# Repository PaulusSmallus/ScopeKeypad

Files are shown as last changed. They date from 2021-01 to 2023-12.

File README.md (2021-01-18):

# ScopeKeypad
This project is to create a keypad for use with a PicoScope. The idea is to have a traditional interface to use with oscilloscope software.

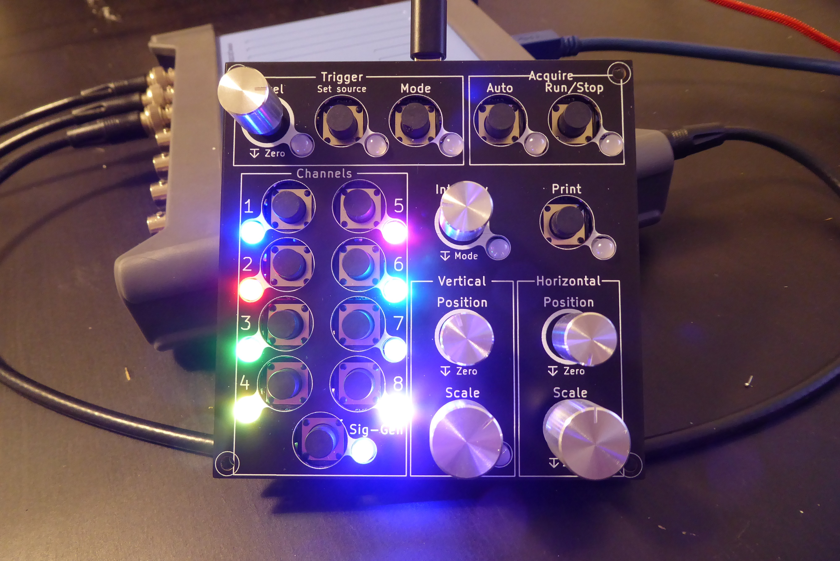
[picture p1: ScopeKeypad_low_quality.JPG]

https://youtu.be/zDIKAT928zg

To use:
Make circuit
	- get the 'main_pcb' made. (in the Hardware/gerbers folder)
	- get one of the 'front_panels' made. There is one for 7mm buttons, and one for 12mm buttons.
	- Solder all the components on
	- Solder JP1 and JP2 depending on if you brought Sparkfun or Worldsemi LEDs (they have different pinouts -_- ).
upload firmware
	- Install Arduino_STM32 ( https://github.com/rogerclarkmelbourne/Arduino_STM32 )
	- Open ScopeKeypad\Firmware\ScopeKeypad_Firmware\ScopeKeypad_Firmware.ino
	- Upload firmware with settings:
		- Board: "Generic STM32F103C"
		- Variant: "STM32F103C8 (20k RAM, 65k Flash)"
		- Upload method: "STLink"
		- CPU Speed(MHz): "72Mhz (normal)"
		- Optimize: "Smallest (default)"
upload shortcut settings to PicoScope software
	- Open PicoScope
	- Click 'Tools'
	- Click 'Preferences...'
	- Open the 'Keyboard' tab
	- Under 'Select keyboard map.', select 'import'
	- Open 'picoscope_shortcuts.pskeys'

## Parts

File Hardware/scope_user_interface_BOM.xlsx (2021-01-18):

Reference | Quantity | Value | Footprint | Datasheet | Cost ea | Cost total | link | lcsc number | part number
C1 C4 C2 C5 C3 C6 C7 C10 C8 C11 C9 C12 C13 C15 C14 C16 | 16 | 1nF | Capacitor_SMD:C_0805_2012Metric |  | £0.0042 | £0.07 | https://lcsc.com/product-detail/Multilayer-Ceramic-Capacitors-MLCC-SMD-SMT_CCTC-TCC0805X7R102M500DT_C713510.html | C713510 | Generic
D20 D18 D19 D23 D21 D22 D24 D25 D1 D2 D3 D4 D5 D6 D7 D8 D9 D10 D11 D12 D13 D14 D15 D16 D17 | 25 | D | Diode_SMD:D_SOD-123F |  | £0.01 | £0.13 | https://lcsc.com/product-detail/Diodes-General-Purpose_Shandong-Jingdao-Microelectronics-1N4007W_C108803.html | C108803 | Generic
D26 D27 D28 D29 D30 D31 D32 D33 D34 D35 D36 D37 D38 D39 D40 D41 D42 D43 | 18 | NeoPixel_THT | LED_THT:LED_D5.0mm-4_RGB | https://www.adafruit.com/product/1938 | £0.12 | £2.15 | https://lcsc.com/product-detail/Others_WS2812D-F5_C190565.html | C190565 | WS2812D-F5
J1 | 1 | USB_B | Connector_USB:USB_B_OST_USB-B1HSxx_Horizontal |  | £0.55 | £0.55 | https://lcsc.com/product-detail/USB-Connectors_MOLEX_47346-0001_47346-0001_C132560.html | C132560 | MOLEX 473460001
R12 R13 R14 R15 R16 R17 R24 R25 R26 R27 R28 R29 R34 R35 R36 R37 | 16 | 100R | Resistor_SMD:R_0805_2012Metric |  |  | £0.00 |  |  | generic
R38 R39 | 2 | 22R | Resistor_SMD:R_0805_2012Metric |  |  | £0.00 |  |  | generic
R9 R6 R10 R7 R11 R8 R21 R18 R22 R19 R23 R20 R32 R30 R33 R31 R1 R2 R3 R4 R5 | 21 | 10k | Resistor_SMD:R_0805_2012Metric |  |  | £0.00 |  |  | generic
SW1 SW2 SW3 SW4 SW5 SW6 SW7 SW8 SW9 SW10 SW11 SW12 SW13 SW14 SW15 SW16 SW17 | 17 | SW_Push | Button_Switch_THT:SW_PUSH-12mm |  | £0.06 | £0.99 | https://lcsc.com/product-detail/Tactile-Switches_USAKRO-UK-B0224-G9-250_C780506.html | C780506UK-B0224-G9-250 | C780506
SW20 SW18 SW19 SW23 SW21 SW22 SW25 SW24 | 8 | Rotary_Encoder_Switch | Rotary_Encoder:RotaryEncoder_Alps_EC11E-Switch_Vertical_H20mm | ~ | £1.67 | £13.35 | https://lcsc.com/product-detail/Coded-Rotary-Switches_ALPS-Electric-EC11E09244AQ_C470753.html | C470753 | EC11E09244AQ
TP1 | 1 | TestPoint |  | ~ |  | £0.00
U1 | 1 | bluepill | footprints:DIP-40_15.24_generic |  |  | £0.00 |  | aliexpress?
 |  |  | rotary dial cap
 |  |  |  |  | TOTAL | £17.22

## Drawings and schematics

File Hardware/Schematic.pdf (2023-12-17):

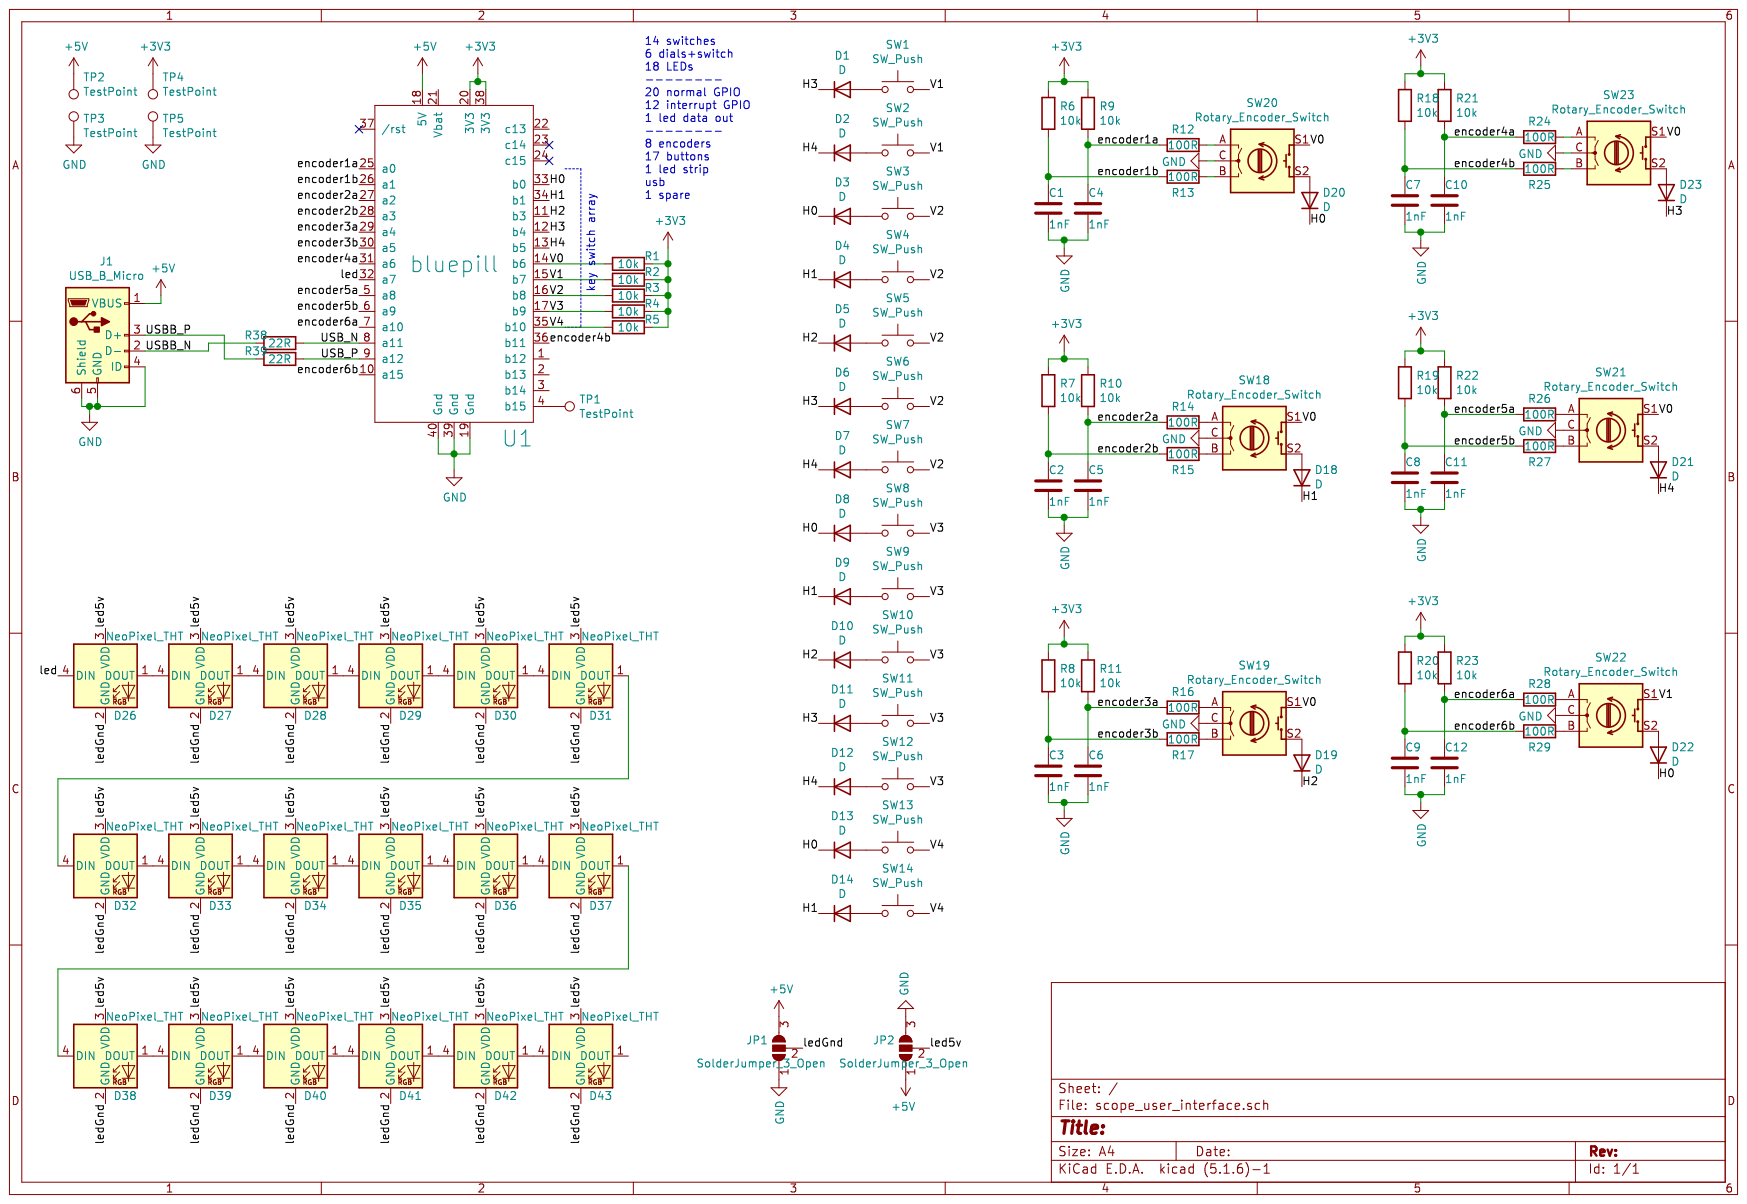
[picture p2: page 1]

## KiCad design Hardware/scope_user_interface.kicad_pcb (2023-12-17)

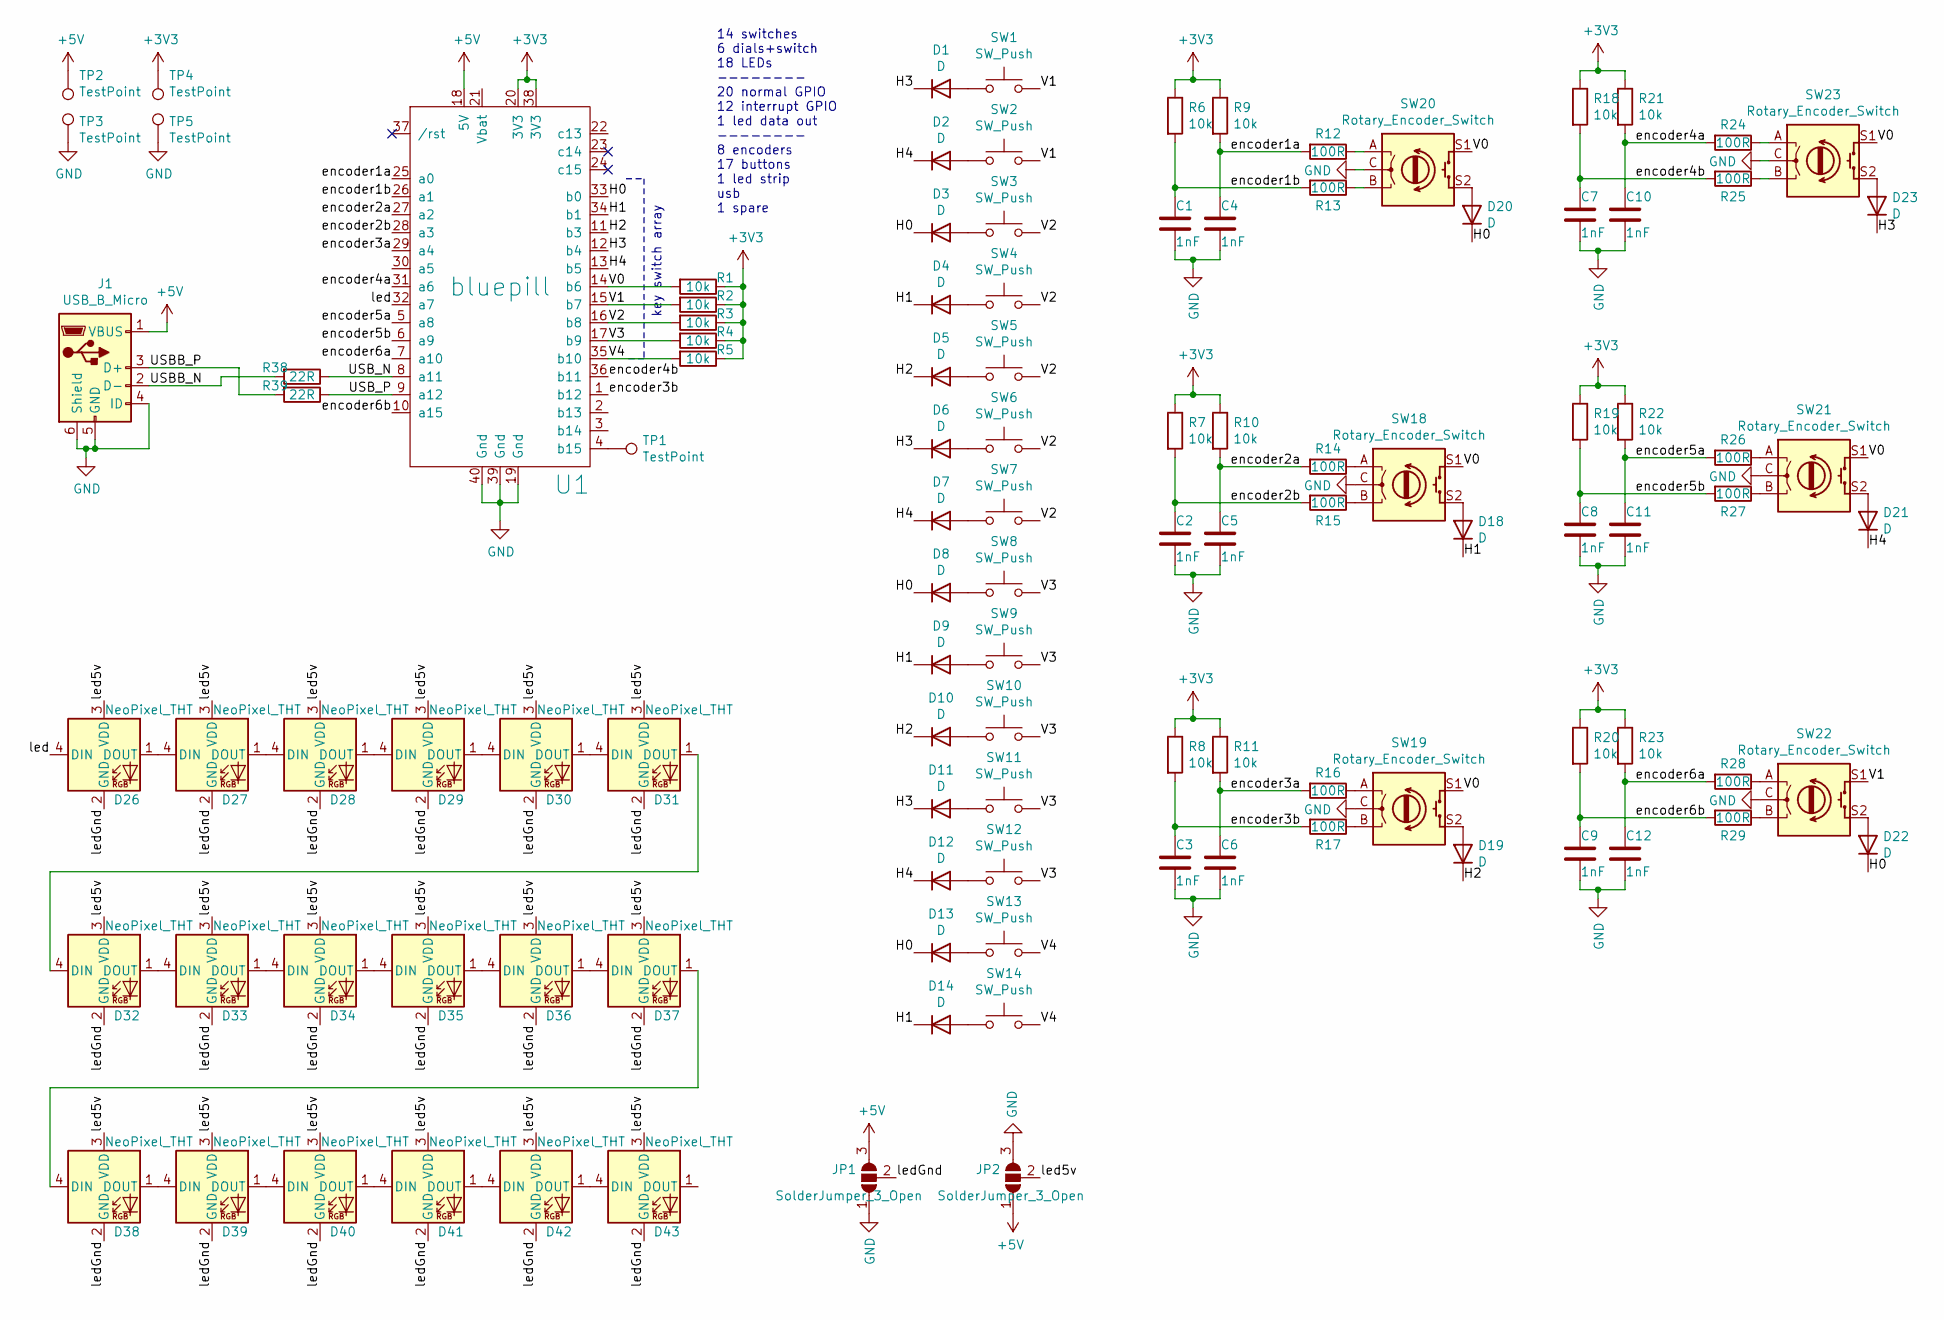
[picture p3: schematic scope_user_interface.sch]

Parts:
C1, C2, C3, C4, C5, C6, C7, C8, C9, C10, C11, C12: 1nF; C_0805_2012Metric
D1, D2, D3, D4, D5, D6, D7, D8, D9, D10, D11, D12, D13, D14, D18, D19, D20, D21, D22, D23: D; D_SOD-123F
D26, D27, D28, D29, D30, D31, D32, D33, D34, D35, D36, D37, D38, D39, D40, D41, D42, D43: NeoPixel_THT; LED_D5.0mm-4_RGB
J1: USB_B_Micro; USB_Micro-B_Molex_47346-0001
JP1, JP2: SolderJumper_3_Open; SolderJumper-3_P1.3mm_Open_RoundedPad1.0x1.5mm
R1, R2, R3, R4, R5, R6, R7, R8, R9, R10, R11, R18, R19, R20, R21, R22, R23: 10k; R_0805_2012Metric
R12, R13, R14, R15, R16, R17, R24, R25, R26, R27, R28, R29: 100R; R_0805_2012Metric
R38, R39: 22R; R_0805_2012Metric
SW1, SW2, SW3, SW4, SW5, SW6, SW7, SW8, SW9, SW10, SW11, SW12, SW13, SW14: SW_Push; SW_PUSH-12mm
SW18, SW19, SW20, SW21, SW22, SW23: Rotary_Encoder_Switch; RotaryEncoder_Alps_EC11E-Switch_Vertical_H20mm
TP1, TP2, TP3, TP4, TP5: TestPoint; TestPoint_Loop_D2.50mm_Drill1.85mm
U1: bluepill; DIP-40_15.24_generic

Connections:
+3V3: R1.1, R2.1, R3.1, R4.1, R5.1, R6.1, R7.1, R8.1, R9.1, R10.1, R11.1, R18.1, R19.1, R20.1, R21.1, R22.1, R23.1, TP4.1, U1.20 (3V3), U1.38 (3V3)
+5V: J1.1 (VBUS), JP1.3 (B), JP2.1 (A), TP2.1, U1.18 (5V)
/H0: D3.1 (K), D8.1 (K), D13.1 (K), D20.1 (K), D22.1 (K), U1.33 (b0)
/H1: D4.1 (K), D9.1 (K), D14.1 (K), D18.1 (K), U1.34 (b1)
/H2: D5.1 (K), D10.1 (K), D19.1 (K), U1.11 (b3)
/H3: D1.1 (K), D6.1 (K), D11.1 (K), D23.1 (K), U1.12 (b4)
/H4: D2.1 (K), D7.1 (K), D12.1 (K), D21.1 (K), U1.13 (b5)
/USBB_N: J1.2 (D-), R38.2
/USBB_P: J1.3 (D+), R39.2
/USB_N: R38.1, U1.8 (a11)
/USB_P: R39.1, U1.9 (a12)
/V0: R1.2, SW18.S1, SW19.S1, SW20.S1, SW21.S1, SW23.S1, U1.14 (b6)
/V1: R2.2, SW1.2, SW2.2, SW22.S1, U1.15 (b7)
/V2: R3.2, SW3.2, SW4.2, SW5.2, SW6.2, SW7.2, U1.16 (b8)
/V3: R4.2, SW8.2, SW9.2, SW10.2, SW11.2, SW12.2, U1.17 (b9)
/V4: R5.2, SW13.2, SW14.2, U1.35 (b10)
/encoder1a: C4.1, R9.2, R12.2, U1.25 (a0)
/encoder1b: C1.1, R6.2, R13.2, U1.26 (a1)
/encoder2a: C5.1, R10.2, R14.2, U1.27 (a2)
/encoder2b: C2.1, R7.2, R15.2, U1.28 (a3)
/encoder3a: C6.1, R11.2, R16.2, U1.29 (a4)
/encoder3b: C3.1, R8.2, R17.2, U1.1 (b12)
/encoder4a: C10.1, R21.2, R24.2, U1.31 (a6)
/encoder4b: C7.1, R18.2, R25.2, U1.36 (b11)
/encoder5a: C11.1, R22.2, R26.2, U1.5 (a8)
/encoder5b: C8.1, R19.2, R27.2, U1.6 (a9)
/encoder6a: C12.1, R23.2, R28.2, U1.7 (a10)
/encoder6b: C9.1, R20.2, R29.2, U1.10 (a15)
/led: D26.4 (DIN), U1.32 (a7)
/led5v: D26.3 (VDD), D27.3 (VDD), D28.3 (VDD), D29.3 (VDD), D30.3 (VDD), D31.3 (VDD), D32.3 (VDD), D33.3 (VDD), D34.3 (VDD), D35.3 (VDD), D36.3 (VDD), D37.3 (VDD), D38.3 (VDD), D39.3 (VDD), D40.3 (VDD), D41.3 (VDD), D42.3 (VDD), D43.3 (VDD), JP2.2 (C)
/ledGnd: D26.2 (GND), D27.2 (GND), D28.2 (GND), D29.2 (GND), D30.2 (GND), D31.2 (GND), D32.2 (GND), D33.2 (GND), D34.2 (GND), D35.2 (GND), D36.2 (GND), D37.2 (GND), D38.2 (GND), D39.2 (GND), D40.2 (GND), D41.2 (GND), D42.2 (GND), D43.2 (GND), JP1.2 (C)
GND: C1.2, C2.2, C3.2, C4.2, C5.2, C6.2, C7.2, C8.2, C9.2, C10.2, C11.2, C12.2, J1.4 (ID), J1.5 (GND), J1.6 (Shield), JP1.1 (A), JP2.3 (B), SW18.C, SW19.C, SW20.C, SW21.C, SW22.C, SW23.C, TP3.1, TP5.1, U1.19 (Gnd), U1.39 (Gnd), U1.40 (Gnd); also elsewhere on the board
unnamed: D1.2 (A), SW1.1
unnamed: D2.2 (A), SW2.1
unnamed: D3.2 (A), SW3.1
unnamed: D4.2 (A), SW4.1
unnamed: D5.2 (A), SW5.1
unnamed: D6.2 (A), SW6.1
unnamed: D7.2 (A), SW7.1
unnamed: D8.2 (A), SW8.1
unnamed: D9.2 (A), SW9.1
unnamed: D10.2 (A), SW10.1
unnamed: D11.2 (A), SW11.1
unnamed: D12.2 (A), SW12.1
unnamed: D13.2 (A), SW13.1
unnamed: D14.2 (A), SW14.1
unnamed: D18.2 (A), SW18.S2
unnamed: D19.2 (A), SW19.S2
unnamed: D20.2 (A), SW20.S2
unnamed: D21.2 (A), SW21.S2
unnamed: D22.2 (A), SW22.S2
unnamed: D23.2 (A), SW23.S2
unnamed: D26.1 (DOUT), D27.4 (DIN)
unnamed: D27.1 (DOUT), D28.4 (DIN)
unnamed: D28.1 (DOUT), D29.4 (DIN)
unnamed: D29.1 (DOUT), D30.4 (DIN)
unnamed: D30.1 (DOUT), D31.4 (DIN)
unnamed: D31.1 (DOUT), D32.4 (DIN)
unnamed: D32.1 (DOUT), D33.4 (DIN)
unnamed: D33.1 (DOUT), D34.4 (DIN)
unnamed: D34.1 (DOUT), D35.4 (DIN)
unnamed: D35.1 (DOUT), D36.4 (DIN)
unnamed: D36.1 (DOUT), D37.4 (DIN)
unnamed: D37.1 (DOUT), D38.4 (DIN)
unnamed: D38.1 (DOUT), D39.4 (DIN)
unnamed: D39.1 (DOUT), D40.4 (DIN)
unnamed: D40.1 (DOUT), D41.4 (DIN)
unnamed: D41.1 (DOUT), D42.4 (DIN)
unnamed: D42.1 (DOUT), D43.4 (DIN)
unnamed: R12.1, SW20.A
unnamed: R13.1, SW20.B
unnamed: R14.1, SW18.A
unnamed: R15.1, SW18.B
unnamed: R16.1, SW19.A
unnamed: R17.1, SW19.B
unnamed: R24.1, SW23.A
unnamed: R25.1, SW23.B
unnamed: R26.1, SW21.A
unnamed: R27.1, SW21.B
unnamed: R28.1, SW22.A
unnamed: R29.1, SW22.B
unnamed: TP1.1, U1.4 (b15)

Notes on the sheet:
14 switches 6 dials+switch 18 LEDs -------- 20 normal GPIO 12 interrupt GPIO 1 led data out -------- 8 encoders 17 buttons 1 led strip usb 1 spare
key switch array

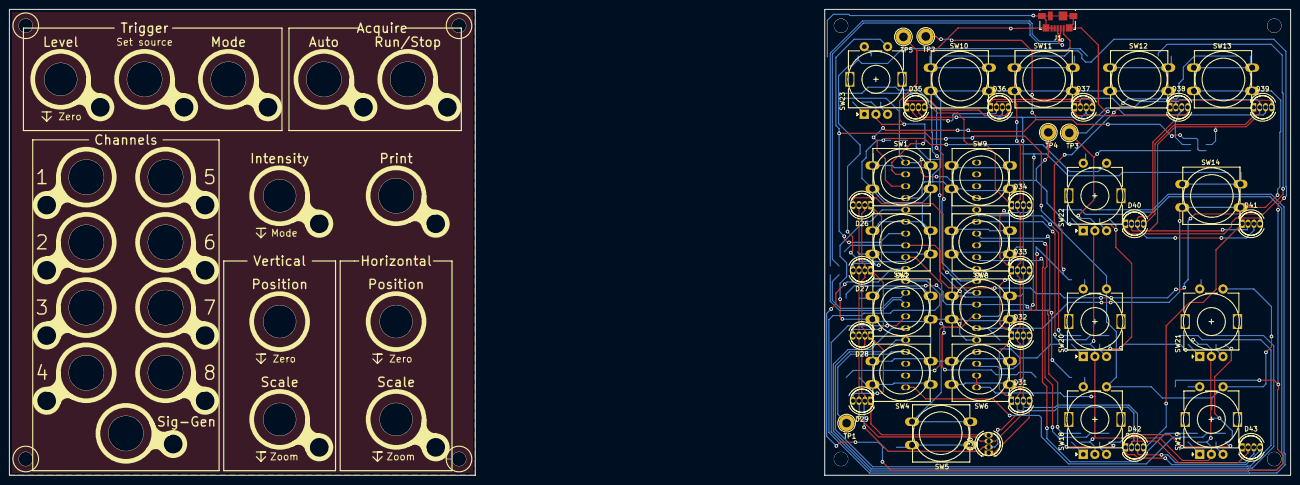
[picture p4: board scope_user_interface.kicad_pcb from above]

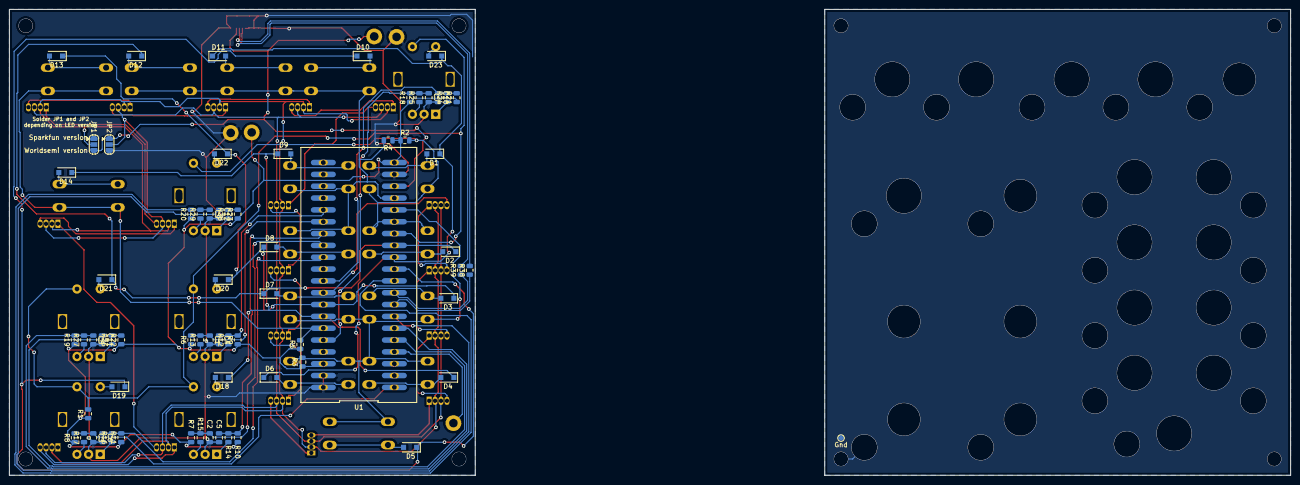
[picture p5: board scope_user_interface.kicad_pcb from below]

Board: 2 copper layers, 100.0 x 100.0 mm, 111 parts (67 on the bottom side), 82 nets.

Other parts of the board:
Gnd: TestPoint_Pad_D1.0mm

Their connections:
GND: Gnd.1; also elsewhere on the board

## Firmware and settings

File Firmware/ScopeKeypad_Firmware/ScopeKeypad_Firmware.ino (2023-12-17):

/*-----------------------NOTES-----------------------
 * requires: https://github.com/rogerclarkmelbourne/Arduino_STM32
 * 
 * TODO:  Change keyboard shortcuts from using 'Alt', as this sometimes causes issues. Use 'Ctrl' and 'Shift' only.
 *        Redo firmware, but with better way of selecting different options.
 *---------------------------------------------------
 */


//**************************************************************
//* include one of these options, depending on software
//**************************************************************

#include "Picoscope.h"
//#include "Pulseview.h"

//*************************************************************


#include <USBComposite.h>
#include <WS2812B.h>

USBHID HID;
HIDKeyboard Keyboard(HID);
USBCompositeSerial CompositeSerial;

#define NUM_LEDS 18
WS2812B strip = WS2812B(NUM_LEDS);
int lo_led[][3] = {{0,0,0},{0,0,0},{0,0,0},{0,0,0},{0,0,0},{0,0,0},{0,2,0},{0,0,0},{0,0,0},{0, 0, 51},{0, 51, 0},{51, 0, 0},{51, 51, 0},{10, 10, 10},{0, 25, 51},{10, 10, 10},{51, 0, 51},{0, 51, 25},{0,0,0},{0,0,0},{0,0,0},{0,0,0},{0,0,0},{0,0,0},{0,0,0},{0,0,0},{0,0,0}};
int hi_led[][3] = {{0,0,0},{0,0,0},{0,0,0},{0,0,0},{0,0,0},{0,0,0},{0,30,0},{0,0,0},{0,0,0},{0, 0,102},{0,102,0},{102,0, 0},{102,102,0},{30, 30, 30},{0, 51, 102},{30, 30, 30},{102,0,102},{0,102, 51},{0,0,0},{0,0,0},{0,0,0},{0,0,0},{0,0,0},{0,0,0},{0,0,0},{0,0,0},{0,0,0}};

int output_buttons[5] = {PB0, PB1, PB3, PB4, PB5};
int input_buttons[5] = {PB6, PB7, PB8, PB9, PB10};
int encoderA_inputs[6] = {PA0, PA2, PA4, PA6, PA8, PA10};
int encoderB_inputs[6] = {PA1, PA3, PB12, PB11, PA9, PA15};

bool channelEnabled [9] = {0,0,0,0,0,0,0,0,0};
char channelSelected = 0; //0 is nothing selected

int8_t buttonToLed[26] = {0,0,0,0,0,0,3,0,0,17,16,15,14,13,12,11,10,9,0,0,0,0,0,0,0,0};
int8_t encoderToLed[6] = {0,0,0,0,0,0};
int8_t lookup_table[] = {0,-1,1,0,1,0,0,-1,-1,0,0,1,0,1,-1,0};
char prev_butt = '!';
int8_t instrumentMode = 0;

long enc_count[6] = {0,0,0,0,0,0};
long enc_count_old[6] = {0,0,0,0,0,0};
//volatile long enc_count = 0;
//volatile long enc_count_old = 0;

void encoder_isr_0() {
    //static int8_t lookup_table[] = {0,-1,1,0,1,0,0,-1,-1,0,0,1,0,1,-1,0};
    static uint8_t enc_val_0 = 0;
    
    enc_val_0 = enc_val_0 << 2;
    enc_val_0 = enc_val_0 | (digitalRead(encoderA_inputs[0])) | (digitalRead(encoderB_inputs[0])<<1);
    enc_count[0] = enc_count[0] + lookup_table[enc_val_0 & 0b1111];
}
void encoder_isr_1() {
    static uint8_t enc_val_1 = 0;
    enc_val_1 = enc_val_1 << 2;
    enc_val_1 = enc_val_1 | (digitalRead(encoderA_inputs[1])) | (digitalRead(encoderB_inputs[1])<<1);
    enc_count[1] = enc_count[1] + lookup_table[enc_val_1 & 0b1111];
}
void encoder_isr_2() {
    static uint8_t enc_val_2 = 0;
    enc_val_2 = enc_val_2 << 2;
    enc_val_2 = enc_val_2 | (digitalRead(encoderA_inputs[2])) | (digitalRead(encoderB_inputs[2])<<1);
    enc_count[2] = enc_count[2] + lookup_table[enc_val_2 & 0b1111];
}
void encoder_isr_3() {
    static uint8_t enc_val_3 = 0;
    enc_val_3 = enc_val_3 << 2;
    enc_val_3 = enc_val_3 | (digitalRead(encoderA_inputs[3])) | (digitalRead(encoderB_inputs[3])<<1);
    enc_count[3] = enc_count[3] + lookup_table[enc_val_3 & 0b1111];
}
void encoder_isr_4() {
    static uint8_t enc_val_4 = 0;
    enc_val_4 = enc_val_4 << 2;
    enc_val_4 = enc_val_4 | (digitalRead(encoderA_inputs[4])) | (digitalRead(encoderB_inputs[4])<<1);
    enc_count[4] = enc_count[4] + lookup_table[enc_val_4 & 0b1111];
}
void encoder_isr_5() {
    static uint8_t enc_val_5 = 0;
    enc_val_5 = enc_val_5 << 2;
    enc_val_5 = enc_val_5 | (digitalRead(encoderA_inputs[5])) | (digitalRead(encoderB_inputs[5])<<1);
    enc_count[5] = enc_count[5] + lookup_table[enc_val_5 & 0b1111];
}


int buttons()
{  
  for (int j=0;j<5;j++)
  {
    digitalWrite(output_buttons[0], HIGH);
    digitalWrite(output_buttons[1], HIGH);
    digitalWrite(output_buttons[2], HIGH);
    digitalWrite(output_buttons[3], HIGH);
    digitalWrite(output_buttons[4], HIGH);
    digitalWrite(output_buttons[j], LOW);
    for (int i=0;i<5;i++){
      if(digitalRead(input_buttons[i])==LOW)return(5*i+j+1);
    }
  }
  digitalWrite(output_buttons[0], HIGH);
  digitalWrite(output_buttons[1], HIGH);
  digitalWrite(output_buttons[2], HIGH);
  digitalWrite(output_buttons[3], HIGH);
  digitalWrite(output_buttons[4], HIGH);
  return 0;
}


void setup() {
  disableDebugPorts();
  for (int j=0;j<5;j++) //buttons
  {
    pinMode(output_buttons[j], OUTPUT);
    pinMode(input_buttons[j], INPUT_PULLUP);
  }
  for (int j=0;j<6;j++) //encoders
  {
    pinMode(encoderA_inputs[j], INPUT);
    //attachInterrupt(encoderA_inputs[j],encoder_isr,CHANGE);
    pinMode(encoderB_inputs[j], INPUT);
    //attachInterrupt(encoderB_inputs[j],encoder_isr,CHANGE);
  }
  attachInterrupt(encoderA_inputs[0],encoder_isr_0,CHANGE);
  attachInterrupt(encoderB_inputs[0],encoder_isr_0,CHANGE);
  attachInterrupt(encoderA_inputs[1],encoder_isr_1,CHANGE);
  attachInterrupt(encoderB_inputs[1],encoder_isr_1,CHANGE);
  attachInterrupt(encoderA_inputs[2],encoder_isr_2,CHANGE);
  attachInterrupt(encoderB_inputs[2],encoder_isr_2,CHANGE);
  attachInterrupt(encoderA_inputs[3],encoder_isr_3,CHANGE);
  attachInterrupt(encoderB_inputs[3],encoder_isr_3,CHANGE);
  attachInterrupt(encoderA_inputs[4],encoder_isr_4,CHANGE);
  attachInterrupt(encoderB_inputs[4],encoder_isr_4,CHANGE);
  attachInterrupt(encoderA_inputs[5],encoder_isr_5,CHANGE);
  attachInterrupt(encoderB_inputs[5],encoder_isr_5,CHANGE);
  //pinMode(PC13, INPUT);
  strip.begin();// Sets up the SPI
  strip.show();// Clears the strip, as by default the strip data is set to all LED's off.
  
  //HID.begin(HID_KEYBOARD);
  HID.begin(CompositeSerial, HID_KEYBOARD);
  while (!USBComposite);
  Keyboard.begin(); // useful to detect host capslock state and LEDs
  CompositeSerial.println("hi");
  
}

void loop() {
  loopy();
}

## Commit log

2021-01-18 first upload
    [front_panel-B_Cu.gbr, front_panel-B_Mask.gbr, front_panel-B_Paste.gbr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]
2021-01-18 main upload
    [front_panel-B_Cu.gbr, front_panel-B_Mask.gbr, front_panel-B_Paste.gbr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]
2021-01-19 added schematic pdf
2021-01-19 Changed encoder3b to PB12
    [scope_user_interface-B_Cu.gbr, scope_user_interface-B_Mask.gbr, scope_user_interface-B_Paste.gbr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]
2023-12-17 update for picoscope
    [scope_user_interface-B_Cu.gbr, scope_user_interface-B_Mask.gbr, scope_user_interface-B_Paste.gbr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]
